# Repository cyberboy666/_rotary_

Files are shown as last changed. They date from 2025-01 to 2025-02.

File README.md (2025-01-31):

# _rotary_

### a voltage controlled fader module for V-4EX, V-8, and V-4 video mixers - created in collaboration with [autr](https://autr.tv)



- this circuit is distributed by __UNDERSCORES__ - _an open video hardware label_ : it is available to purchase - as a pcb, kit or assembled unit - at [underscores.shop](https://underscores.shop/_rotary_/)
- the schematic for the circuit can be found [here](/hardware/schematic.pdf)
- the pcb gerber files for the lastest version can be found [here](/hardware/gerber_latest.zip)
- interactive BOM is [here](https://htmlpreview.github.io/?https://github.com/cyberboy666/_rotary_/blob/main/hardware/bom/ibom.html)
- consider [donating](https://opencollective.com/underscores) to the underscores project to help us continue creating for the commons

Screenshot from 2024-09-18 08-32-34

## demo video

(https://videos.scanlines.xyz/w/wgZMKsMME6ki3BdQGAwYhb)

## background

<details><summary>background</summary>

A known mod to the Roland/Edirol V-4 video mixer is to add cv control of fader position. Since this mixer (and also the V-8 and V-4EX that followed it) has a swappable t-bar we decided to turn this mod into a standalone module. In addition to cv control we also added an envelope follower so that audio can be directly passed in and a nice rotary manual fader



_the offical swappable __CROSS FADER__ MODULE [from roland](https://proav.roland.com/global/products/v-4cf/)_

roland_v4_cv_mod

_an example of a cv mod built into V-4 mixer (can see protection diodes mounted on perfboard inside the case)_

</details>

# documentation

this project is fully _open-source hardware_ - all the files required to build it are included in this repo for free. if you have the time and/or skill you can contribute back by collaborating on / testing new designs, improving these docs, making demo videos/other creative content etc. you can also support the project financially by [donating](https://opencollective.com/underscores) directing, or purchasing through the [web shop](https://underscores.shop).

depending on whether you are going fully diy or buying an assembled and tested unit, some of the following guides will be relavent to you. the flow would be:

## ordering parts

<details><summary><b>parts sourcing guide (w/ notes on pcb fabracation )</b> - start here if you are building fully from scatch or have purchased a pcb</summary>

i try to source all the parts i can from either:
- [tayda](https://www.taydaelectronics.com/) ; cheaper for common parts like resistors etc, also good for mechanical parts like switches and buttons
- [mouser](https://www.mouser.de/) ; has lots more options, speciality video ic's, can sometimes cost more (free shipping on orders over 50euros)
- other ; ocationally there will be parts which will need to be sourced elsewhere - usaully either aliexpress, ebay or amazon etc...

take a look at the [full_bom](/hardware/bom/full_bom.csv) for this project to see where i am sourcing each part from

## import into tayda

- go to the [tayda quick order](https://www.taydaelectronics.com/quick-order/) and in bottom corner choose _add from file_
- select the file [tayda_bom.csv](../hardware/bom/tayda_bom.csv) in the BOM folder (you will have to download it first or clone this repo)
- after importing select _add to cart_
- __NOTE:__ the minimum value for resistors is 10, so you may need to modify these values to add to cart (or if they are already modified here you will need to see the  full_bom for actual part QTY) 

- OPTIONAL: it is a good idea to add some dip-ic sockets and 2.54pin headers/sockets to your tayda order if you dont have them around already
  
## import into mouser

- go to [mouser bom tool](https://nz.mouser.com/Bom/) and click _upload spreadsheet_
- select the file [mouser_bom.csv](../hardware/bom/mouser_bom.csv) in this folder (you will have to download it first or clone this repo), then _upload my spreadsheet_ and _next_
- ensure that __Mouser Part Number__ is selected in the dropdown above the first row, then _next_, _process_
- if everything looks correct can now put _add to basket_

# ordering pcbs

you can support this project by buying individual pcbs from the [shop](https://underscores.shop). if you would rather have pcbs fabricated from gerbers directly the file you need is [here](/hardware/gerber_latest.zip)

- i get my pcbs fabricated from [jlcpcb](https://cart.jlcpcb.com/quote) - 5 is the minumum order per design
- upload the zip file with the `add gerber file` button
- the default settings are mostly fine - set the __PCB Qty__ and __PCB Color__ settings (you can check that the file looks correct with pcb veiwer)
- it may be best to combine orders with other pcbs you want to have fab'd since the shipping can cost more than the items - also orginising group buys is a good way to distribute the extra pcbs /costs 
  
i often use jlcpcb because they are reliable, cheap and give you an option of colours. remember though that the cheapest Chinese fab houses are not always the most ethical or environmently friendly - if you can afford it consider supporting local companies. 

  </details>
  
## assembly guide
  
<details><summary><b>assembly guide</b> - start here if you have purchased a diy kit</summary>

## interactive BOM for build guiding

follow this link to view the [interactive BOM](https://htmlpreview.github.io/?https://github.com/cyberboy666/_rotary_/blob/main/hardware/bom/ibom.html)

## general solder advice

- remember to heat pad first (2-3seconds), then add solder, then continue to heat (1-2seconds)

- Checkout the web-comic [soldering is easy](https://mightyohm.com/files/soldercomic/FullSolderComic_EN.pdf) for more soldering advice

## general order of assembly

- in general while assembling i start placing resistors and capacitors first. placing 5 - 10 components at a time and then flipping the board to solder them and trim the legs etc.
- next i would do diodes, transistors and ic's - taking care that these are placed in the right direction (using a ic socket can be useful)
- finally i place the interface parts - rca jacks, power jack, pots and switches - make sure these have lots of solder on for structural stablity

</details>

## operating guide
  
<details><summary><b>operating guide</b> - start here if you have purchased an assembled unit</summary>



</details>

### more info

<details><summary><b>how the circuit works</b></summary>

</details>

<details><summary><b>contributing guide</b></summary>
  
if you would like to contribute back to these projects in some way but dont know how the best thing (for now) would be to reach out to me directly ( tim@cyberboy666.com or @cyberboy666 on scanlines forum) - i will be happy to help
  
</details>

## credits & more info

This circuit is distributed through UNDERSCORES – open video hardware label – visit [underscores.shop](https://underscores.shop) for more info

The pcb was designed using KICAD , the booklet was created in LibreOffice Draw

Everything from gerbers, cad files, panels and documentation is freely available online and distributed under CC-BY-SA / open-source licenses – help us contribute to the commons !

Ask any questions or start discussions related to this project on the [scanlines.xyz](https://scanlines.xyz) forum – an online community space dedicated to diy av / electronic media art

You can contact me directly at tim (at) cyberboy666 (dot) com 
Please get in touch if you are interested in hosting a workshop !



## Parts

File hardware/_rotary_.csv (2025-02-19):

Reference | Quantity | Value | Footprint | Datasheet | Footprint | Datasheet | Description | Sim.Device | Sim.Pins
C1 C2 | 2 | 0.1u | Capacitor_THT:C_Disc_D7.0mm_W2.5mm_P5.00mm |  | Capacitor_THT:C_Disc_D7.0mm_W2.5mm_P5.00mm
C3 | 1 | 1u | Capacitor_THT:C_Disc_D7.0mm_W2.5mm_P5.00mm |  | Capacitor_THT:C_Disc_D7.0mm_W2.5mm_P5.00mm
D1 D2 | 2 | bat46 | Diode_THT:D_DO-34_SOD68_P7.62mm_Horizontal |  | Diode_THT:D_DO-34_SOD68_P7.62mm_Horizontal
D3 D4 D5 | 3 | 1n4148 | Diode_THT:D_DO-34_SOD68_P7.62mm_Horizontal |  | Diode_THT:D_DO-34_SOD68_P7.62mm_Horizontal |  |  | D | 1=K 2=A
J1 | 1 | mono_jack_3.5mm | lib_fp:Jack_3.5mm_QingPu_WQP-PJ398SM_Vertical_CircularHoles |  | lib_fp:Jack_3.5mm_QingPu_WQP-PJ398SM_Vertical_CircularHoles
J2 | 1 | jst_xa_3 | Connector_JST:JST_XA_B03B-XASK-1-A_1x03_P2.50mm_Vertical |  | Connector_JST:JST_XA_B03B-XASK-1-A_1x03_P2.50mm_Vertical
R1 R2 R3 R4 R5 R15 | 6 | 1k | Resistor_THT:R_Axial_DIN0207_L6.3mm_D2.5mm_P7.62mm_Horizontal |  | Resistor_THT:R_Axial_DIN0207_L6.3mm_D2.5mm_P7.62mm_Horizontal
R11 R12 | 2 | 20k | Resistor_THT:R_Axial_DIN0207_L6.3mm_D2.5mm_P7.62mm_Horizontal |  | Resistor_THT:R_Axial_DIN0207_L6.3mm_D2.5mm_P7.62mm_Horizontal
R13 | 1 | 2.4k | Resistor_THT:R_Axial_DIN0207_L6.3mm_D2.5mm_P7.62mm_Horizontal |  | Resistor_THT:R_Axial_DIN0207_L6.3mm_D2.5mm_P7.62mm_Horizontal
R6 R7 | 2 | 100 | Resistor_THT:R_Axial_DIN0207_L6.3mm_D2.5mm_P7.62mm_Horizontal |  | Resistor_THT:R_Axial_DIN0207_L6.3mm_D2.5mm_P7.62mm_Horizontal
R8 R9 R10 R14 | 4 | 10k | Resistor_THT:R_Axial_DIN0207_L6.3mm_D2.5mm_P7.62mm_Horizontal |  | Resistor_THT:R_Axial_DIN0207_L6.3mm_D2.5mm_P7.62mm_Horizontal
RV1 | 1 | 1k_pot_d | lib_fp:Potentiometer_Vertical_Large |  | lib_fp:Potentiometer_Vertical_Large
RV2 | 1 | 5k_pot | lib_fp:Potentiometer_Vertical_Large |  | lib_fp:Potentiometer_Vertical_Large
RV3 | 1 | 100k_pot | lib_fp:Potentiometer_Vertical_Large |  | lib_fp:Potentiometer_Vertical_Large
SW1 | 1 | SW_DPDT_x2 | lib_fp:dpdt_mini_toggle_switch_tayda |  | lib_fp:dpdt_mini_toggle_switch_tayda
U1 | 1 | TLV2372 | Package_DIP:DIP-8_W7.62mm_LongPads | http://www.ti.com/lit/ds/symlink/tlv2375.pdf | Package_DIP:DIP-8_W7.62mm_LongPads | http://www.ti.com/lit/ds/symlink/tlv2375.pdf
U2 | 1 | LM317 | Package_TO_SOT_THT:TO-92_HandSolder | http://www.ti.com/lit/ds/snvs775k/snvs775k.pdf | Package_TO_SOT_THT:TO-92_HandSolder | http://www.ti.com/lit/ds/snvs775k/snvs775k.pdf
U3 | 1 | TLV2374 | Package_DIP:DIP-14_W7.62mm_LongPads |  | Package_DIP:DIP-14_W7.62mm_LongPads

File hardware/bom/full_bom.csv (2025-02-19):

sku | qty | ref | val | vendor
A-4008 | 2 | C1 C2 | 0.1u | tayda
A-321 | 1 | C3 | 1u | tayda
A-1095 | 2 | D1 D2 | bat46 | tayda
A-157 | 3 | D3 D4 D5 | 1n4148 | tayda
A-2563 | 1 | J1 | mono_jack_3.5mm | tayda
A-5505 | 1 | J2 | jst_xa_3 | tayda
A-2200 | 6 | R1 R2 R3 R4 R5 R15 | 1k | tayda
A-2339 | 2 | R11 R12 | 20k | tayda
A-2606 | 1 | R13 | 2.4k | tayda
A-2245 | 2 | R6 R7 | 100 | tayda
A-2203 | 4 | R8 R9 R10 R14 | 10k | tayda
652-PTV09A-4025FB102 | 1 | RV1 | 1k_pot_d | mouser
A-1870 | 1 | RV2 | 5k_pot | tayda
A-5530 | 1 | RV3 | 100k_pot | tayda
A-4568 | 1 | SW1 | SW_DPDT_x2 | tayda
595-TLV2372IP | 1 | U1 | TLV2372 | mouser
A-500 | 1 | U2 | LM317 | tayda
595-TLV2374IN | 1 | U3 | TLV2374 | mouser
https://www.aliexpress.com/item/1005002364189187.html | 2 | - | m3x25mm_screws | aliexpress
https://www.aliexpress.com/item/1005007502691265.html | 2 | - | m3_nuts | aliexpress
A-003 | 1 | - | dip16_socket | tayda
A-001 | 1 | - | dip8_socket | tayda
https://www.aliexpress.com/item/1005001946103576.html | 1 | - | d pot cap | aliexpress

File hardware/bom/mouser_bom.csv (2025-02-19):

sku | qty | ref | val | vendor
652-PTV09A-4025FB102 | 1 | RV1 | 1k_pot_d | mouser
595-TLV2372IP | 1 | U1 | TLV2372 | mouser
595-TLV2374IN | 1 | U3 | TLV2374 | mouser

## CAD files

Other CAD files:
panel_and_circuit_model.FCStd

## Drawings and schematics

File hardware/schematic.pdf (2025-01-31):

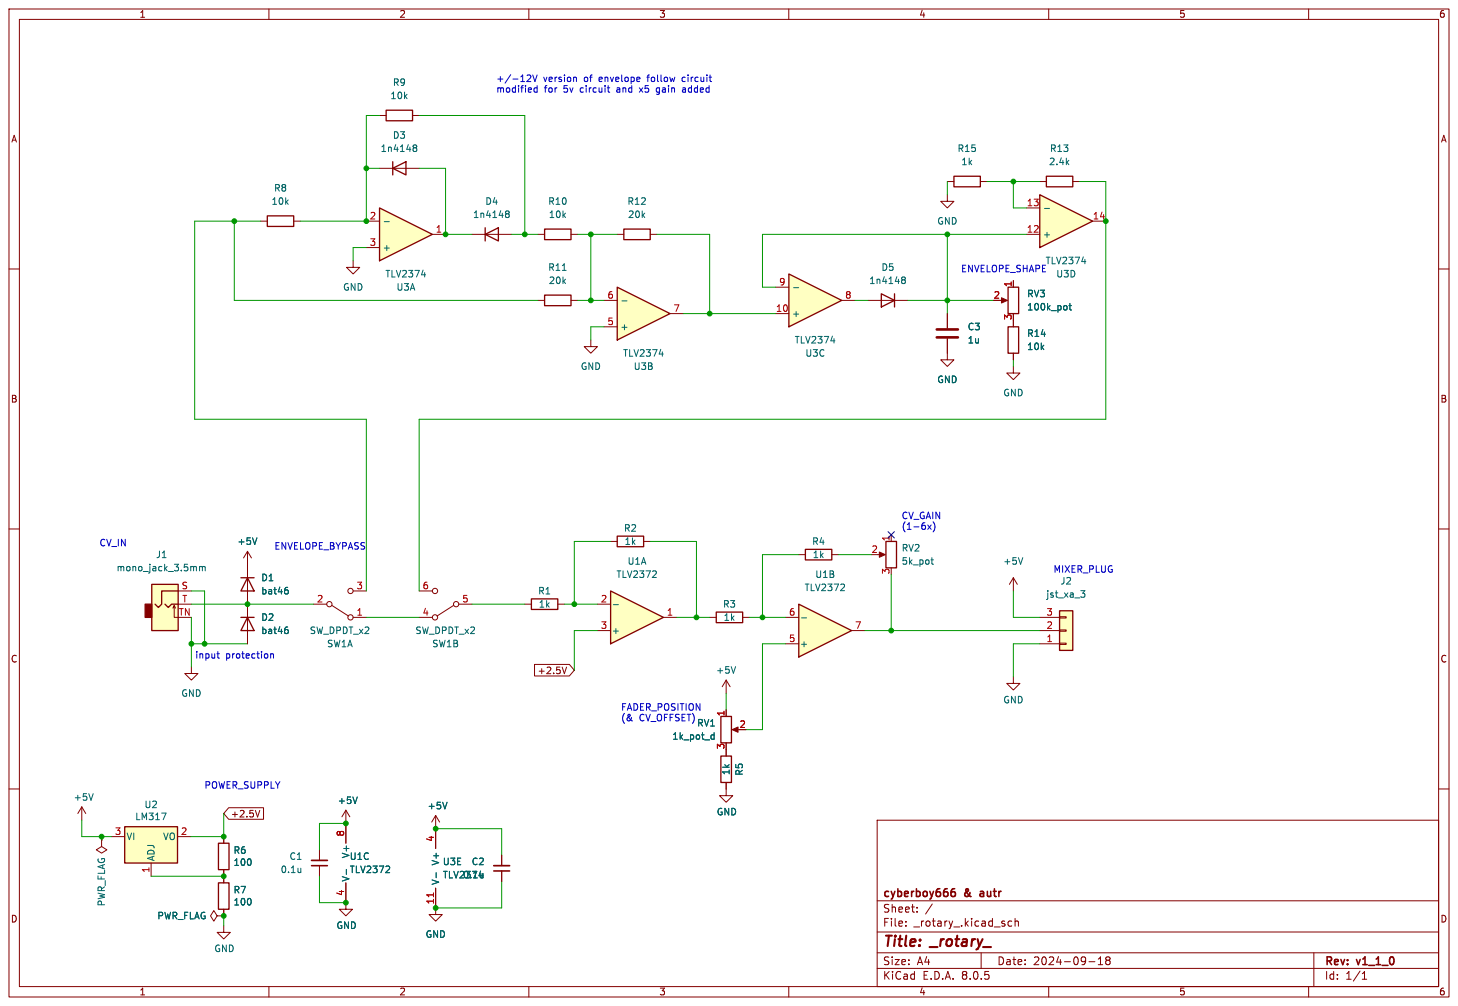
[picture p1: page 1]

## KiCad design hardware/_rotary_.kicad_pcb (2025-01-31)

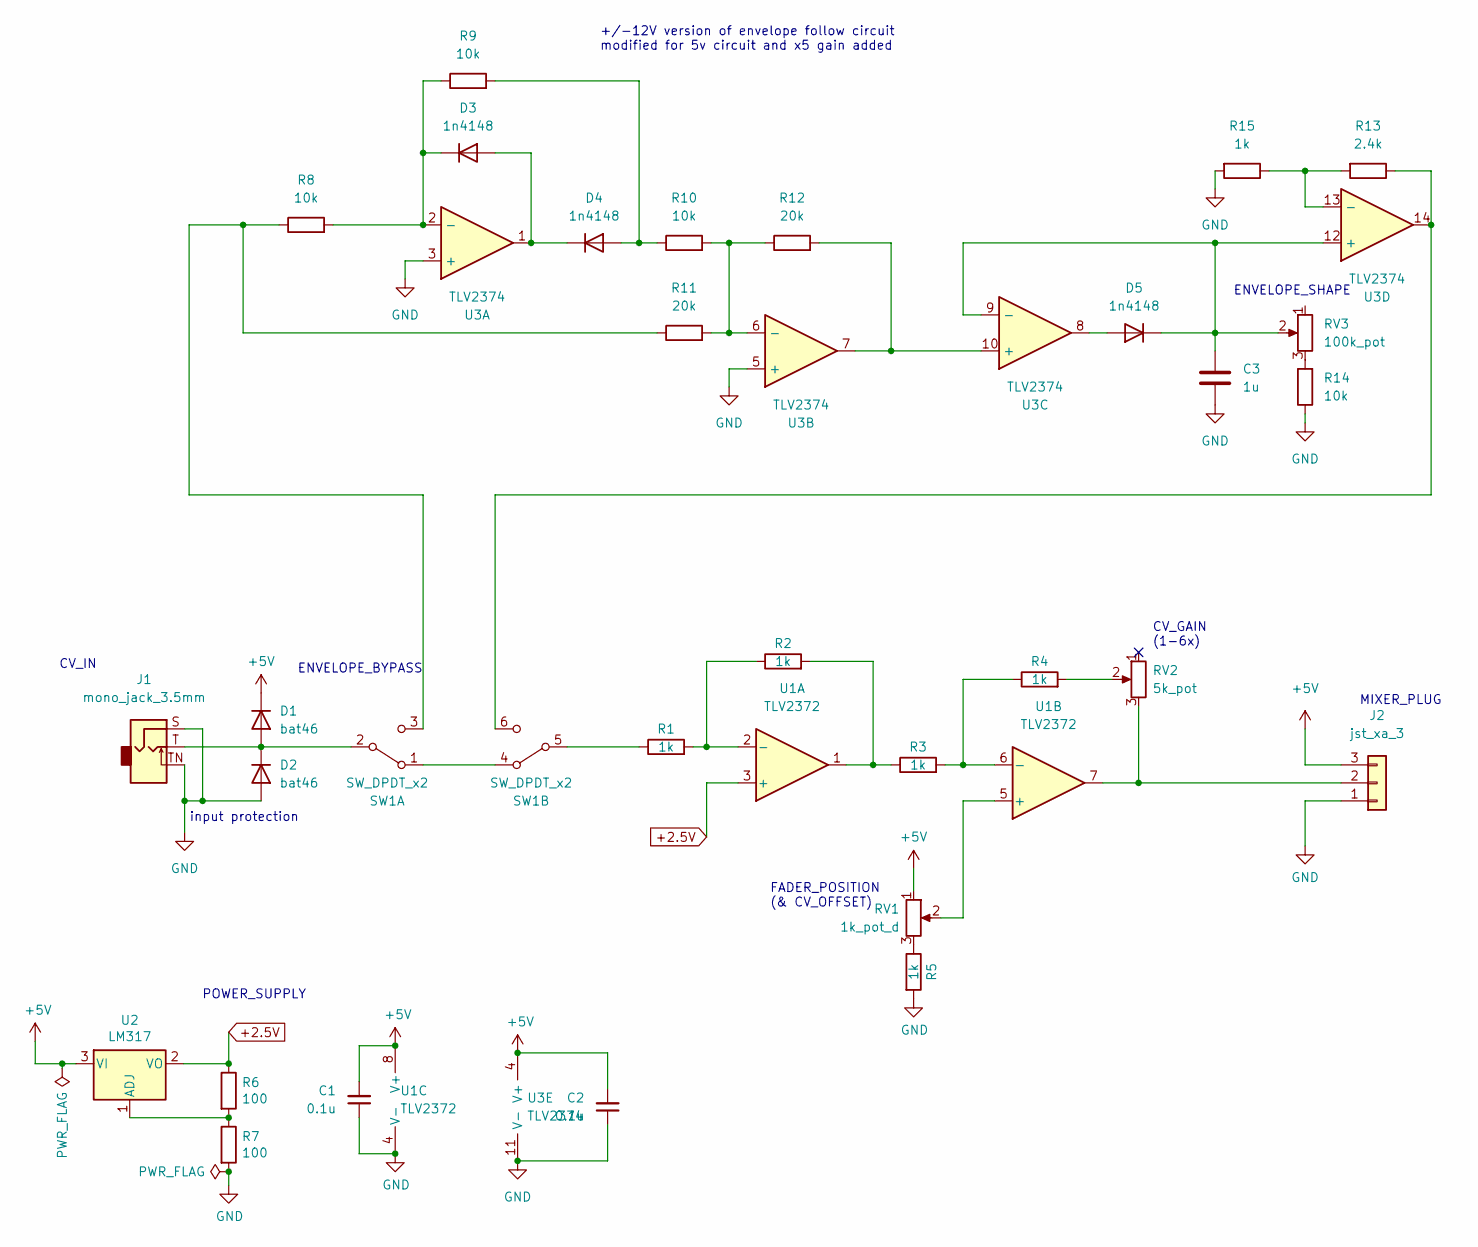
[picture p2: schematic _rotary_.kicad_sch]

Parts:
C1, C2: 0.1u; C_Disc_D7.0mm_W2.5mm_P5.00mm
C3: 1u; C_Disc_D7.0mm_W2.5mm_P5.00mm
D1, D2: bat46; D_DO-34_SOD68_P7.62mm_Horizontal
D3, D4, D5: 1n4148; D_DO-34_SOD68_P7.62mm_Horizontal
J1: mono_jack_3.5mm; Jack_3.5mm_QingPu_WQP-PJ398SM_Vertical_CircularHoles
J2: jst_xa_3; JST_XA_B03B-XASK-1-A_1x03_P2.50mm_Vertical
R1, R2, R3, R4, R5, R15: 1k; R_Axial_DIN0207_L6.3mm_D2.5mm_P7.62mm_Horizontal
R6, R7: 100; R_Axial_DIN0207_L6.3mm_D2.5mm_P7.62mm_Horizontal
R8, R9, R10, R14: 10k; R_Axial_DIN0207_L6.3mm_D2.5mm_P7.62mm_Horizontal
R11, R12: 20k; R_Axial_DIN0207_L6.3mm_D2.5mm_P7.62mm_Horizontal
R13: 2.4k; R_Axial_DIN0207_L6.3mm_D2.5mm_P7.62mm_Horizontal
RV1: 1k_pot_d; Potentiometer_Vertical_Large
RV2: 5k_pot; Potentiometer_Vertical_Large
RV3: 100k_pot; Potentiometer_Vertical_Large
SW1: SW_DPDT_x2; dpdt_mini_toggle_switch_tayda
U1: TLV2372; DIP-8_W7.62mm_LongPads
U2: LM317; TO-92_HandSolder
U3: TLV2374; DIP-14_W7.62mm_LongPads

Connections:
+2.5V: R6.1, U1.3 (+), U2.2 (VO)
+5V: C1.2, C2.2, D1.1 (K), J2.3, RV1.1, U1.8 (V+), U2.3 (VI), U3.4 (V+)
GND: C1.1, C2.1, C3.2, D2.2 (A), J1.S, J1.TN, J2.1, R5.2, R7.2, R14.1, R15.2, U1.4 (V-), U3.3 (+), U3.5 (+), U3.11 (V-)
unnamed: D1.2 (A), D2.1 (K), J1.T, SW1.2 (B)
unnamed: D3.2 (A), D4.1 (K), U3.1
unnamed: D3.1 (K), R8.2, R9.1, U3.2 (-)
unnamed: D4.2 (A), R9.2, R10.1
unnamed: D5.2 (A), U3.8
unnamed: C3.1, D5.1 (K), RV3.2, U3.9 (-), U3.12 (+)
unnamed: J2.2, RV2.3, U1.7
unnamed: R2.2, R3.1, U1.1
unnamed: R4.2, RV2.2
unnamed: R5.1, RV1.3
unnamed: R14.2, RV3.3
unnamed: SW1.1 (A), SW1.4 (A)
unnamed: R8.1, R11.1, SW1.3 (C)
unnamed: R1.1, SW1.5 (B)
unnamed: R13.1, SW1.6 (C), U3.14
unnamed: R1.2, R2.1, U1.2 (-)
unnamed: RV1.2, U1.5 (+)
unnamed: R3.2, R4.1, U1.6 (-)
unnamed: R6.2, R7.1, U2.1 (ADJ)
unnamed: R10.2, R11.2, R12.1, U3.6 (-)
unnamed: R12.2, U3.7, U3.10 (+)
unnamed: R13.2, R15.1, U3.13 (-)

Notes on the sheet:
POWER_SUPPLY
+/-12V version of envelope follow circuit modified for 5v circuit and x5 gain added
ENVELOPE_BYPASS
input protection
CV_IN
MIXER_PLUG
ENVELOPE_SHAPE
CV_GAIN (1-6x)
FADER_POSITION (& CV_OFFSET)

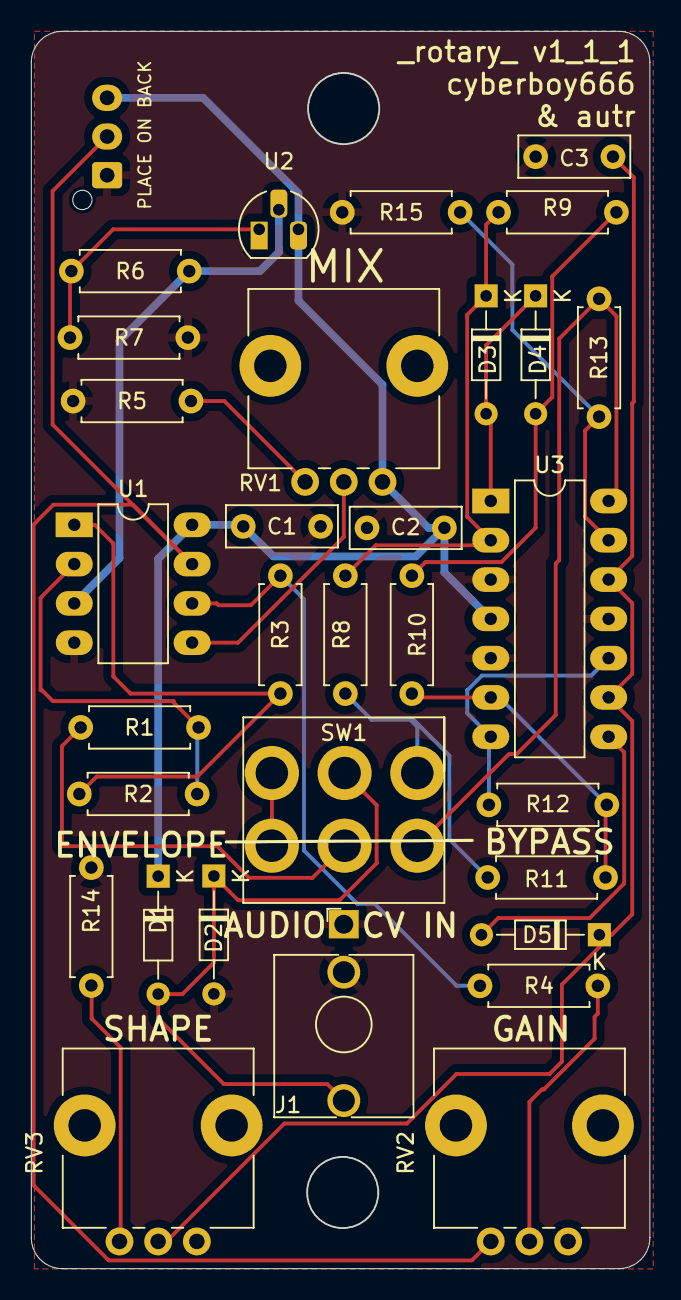
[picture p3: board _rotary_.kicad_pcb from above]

Board: 2 copper layers, 40.0 x 80.0 mm, 32 parts (1 on the bottom side), 25 nets.

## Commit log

2023-06-08 uploading to github
    [_rotary_-B_Cu.gbr, _rotary_-B_Mask.gbr, _rotary_-B_Paste.gbr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]
2024-05-19 updated circuit and panel to include envelope follower
    [_rotary_-B_Cu.gbr, _rotary_-B_Mask.gbr, _rotary_-B_Paste.gbr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]
2024-09-17 preparing v1_1_0 for release
    [_rotary_-B_Cu.gbr, _rotary_-B_Mask.gbr, _rotary_-B_Paste.gbr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]
2024-09-17 tidying up panel folder
    [_rotary_.kicad_pcb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]
2025-01-31 update pcbs and panels
    [_rotary_.kicad_pcb, _rotary_.kicad_sch, panel.kicad_pcb]
2025-02-19 update bom
    [panel-B_Cu.gbr, panel-B_Mask.gbr, panel-B_Paste.gbr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]
2025-02-19 update bomc
    [_rotary_.csv, full_bom.csv, mouser_bom.csv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]
